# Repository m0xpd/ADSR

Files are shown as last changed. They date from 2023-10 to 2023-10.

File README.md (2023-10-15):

# ADSR
A Looping Version of the YuSynth ADSR

# Background

I decided to build a new envelope generator back in December 2022 to supplement / replace my old AR generators made from [MFOS](http://musicfromouterspace.com/) designs and my 
own ["ADSRduino"](https://github.com/m0xpd/ADSRduino).

I already knew Yves Usson's excellent [YuSynth site](https://yusynth.net/Modular/index_en.html) (having published a Eurorack version of the ['Simple VCA'](https://github.com/m0xpd/YuSynth-VCA-for-Eurorack)), and was interested by a comment on 
[Eddy Bergman's website](https://www.eddybergman.com/2020/03/synthesizer-build-part-24-adsr-with.html) about the YuSynth ADSR.

Eddy said:

> "I can say without any doubt that this design is perfect if you want a good and reliable ADSR to pair with your VCA or to drive a filter. " 

That settled it - I would make a Eurorack version of Yves' 7555-based design. However, having added looping to my ADSRduino, 
I decided that I would also like to include the same looping functionality on the new envelope generator. 

So - here it is. A version of the YuSynth 7555 ADSR in 8HP with looping...

<p width=100%, align="center">
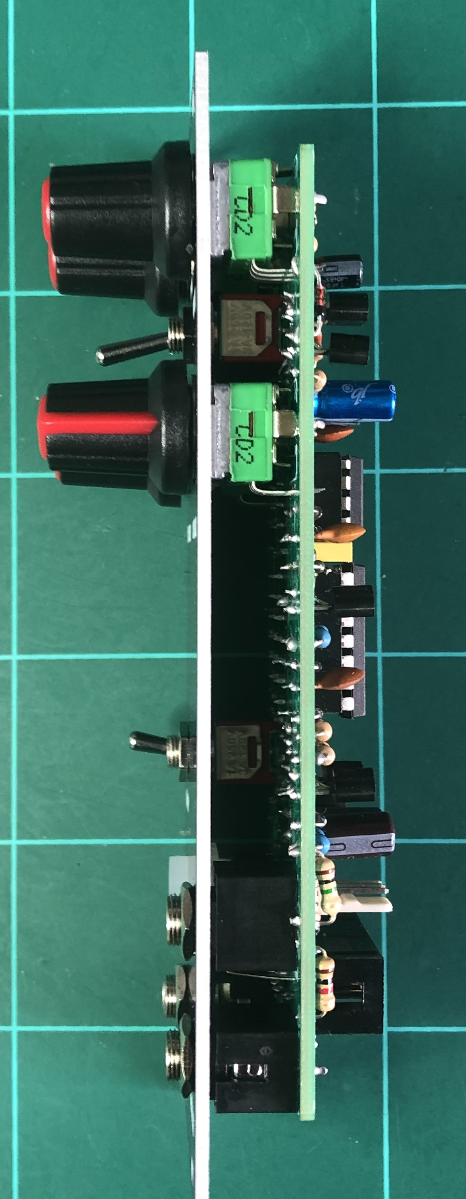
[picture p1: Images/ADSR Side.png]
 &nbsp &nbsp &nbsp &nbsp &nbsp &nbsp &nbsp &nbsp 
</p>

# Circuit Details

The schematic is seen below (click for a full-sized version and/or download from the 'images' folder).

<p width=100%, align="center">
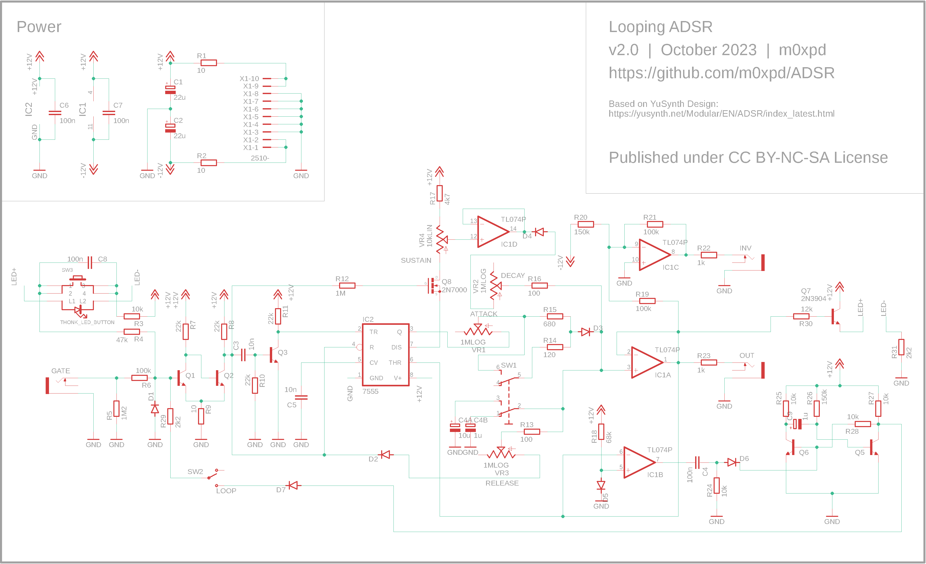
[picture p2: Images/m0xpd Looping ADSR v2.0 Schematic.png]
 
</p>

You will see that I follow Yves' original schematic pretty closely, apart from the addition of the elements required to realise the 
looping functionality. These are:
* a comparator (IC1B) to detect when the envelope falls below the PN junction drop (over D5)
* a positive edge detector (R24/C4/D6) to get a trigger when the envelope falls below the PN junction drop and
* a one-shot monostable multivibrator (Q5,6 etc), to generate a defined pulse from this trigger, 

which is applied via D7 back to the input stage. If the looping switch (SW2) is set appropriately, this pulse can re-trigger the 
envelope and cause 'looping'.

The old-school transistor one-shot is included because I didn't want to add another IC package (having already 'spent' the last stage 
of IC1 on the comparator task).

Other minor departures from Yves' "words and music" include a reduction in input resistor R6 (I had trouble with the specified 1M) and 
substitution of a 2N7000 for Yves' specified BS170 (I see others have had difficuty sourcing these rarer FETs and the garden-variety 
2N7000 works fine). 

I also chose to use once again the lovely [low-profile push button](https://www.thonk.co.uk/shop/low-profile-led-buttons/) as both 
manual gate switch and indicator. It is the right height to work with [Thonkiconns](https://www.thonk.co.uk/shop/thonkiconn/) and [Alpha pots](https://www.thonk.co.uk/shop/alpha-9mm-pots-vertical-t18/), which makes mechanical assembly a breeze.

# Construction Details

Full details of the PCB are given in the [PCB folder](PCB), which includes a .sch and .brd file, developed in EAGLE.

A front panel is decribed by a Kicad project in the [Front Panel folder.](Front%20Panel)

My original boards and Front panel (seen in the images above) were made by JLC, who did their usual competent job. 

The images show the v0.1 boards, which include a Molex KK connector for power which is not on the present V2.0 design. They also have 
different silkscreening, influencing most significantly the licensing...

# Licensing

<p width=100%, align="left">
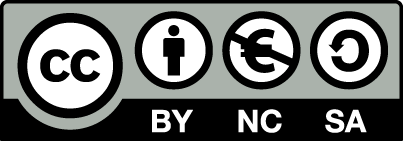
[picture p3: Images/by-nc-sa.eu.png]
 
</p>

Yves is clear on the position with copyright on his website:

> "All circuits, schematics, printed circuit board, panel design and associated data published on (yusynth.net) can be used for private use only." 

and:

> "The projects of (yusynth.net) may be build for personal, private usage or educative purpose. Commercial exploitation of the schematics, circuits, 
front panels and software shown on (yusynth.net), is not permitted without a formal agreement with (Yves Usson)".

Accordingly, **the copyright for the core of this ADSR circuit rests with Yves and no commercial exploitation is permitted**.

I have reflected this in the [License](LICENSE.txt) for the looping Eurorack version presented in this repository.

This work is licensed under a
[Creative Commons Attribution-NonCommercial-ShareAlike 4.0 International License.](https://creativecommons.org/licenses/by-nc-sa/4.0/deed.en)

# Specifications

The looping ADSR is 8HP wide and extends 25mm behind the front panel.

It consumes:

7.1mA from the 12V rail (max current in looping mode; quiescent current drain is 3.7mA)  

1.1mA from the -12V rail (in all conditions) 

nothing from the 5V rail.

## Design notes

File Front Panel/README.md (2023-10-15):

This folder contains a design for a Front Panel for the Looping ADSR envelope generator.

<p width=100%, align="center">
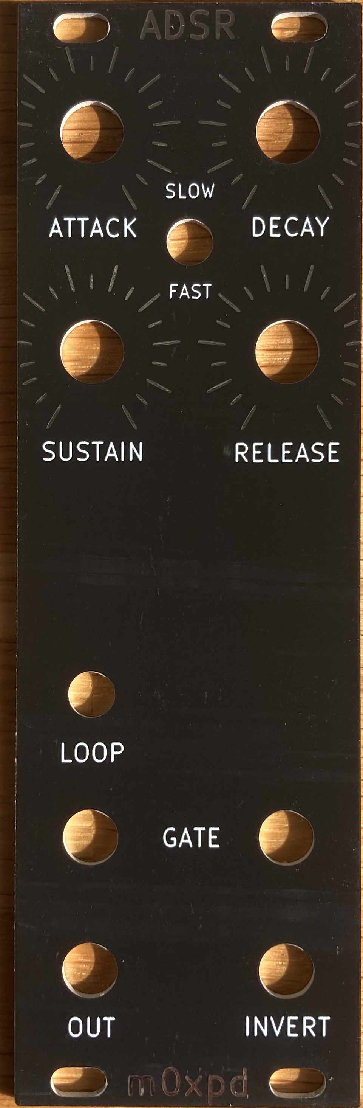
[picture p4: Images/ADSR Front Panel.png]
 
</p>

The panel design is expressed as a Kicad project.

The prototype panel in the image above was maanufactured by JLC. Their charges for aluminium panels has increased dramatically 
since the prototype was produced - alternatives in PCB material might be preferred!

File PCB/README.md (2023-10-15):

This folder contains design files for the m0xpd Looping ADSR.

There is a schematic file and a board file, developed in the EAGLE editor.

There is also a [BoM](m0xpd%20Looping%20ADSR%20v2.0%20Bill%20of%20Materials.txt), in the EAGLE's rather clumsy format.

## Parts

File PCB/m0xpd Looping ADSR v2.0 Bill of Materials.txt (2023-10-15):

Partlist exported from /Users/pauldarlington/Documents/EAGLE/projects/555 ADSR/m0xpdLooping ADSR v2.0.sch at 15/10/2023 13:20

Part Value            Device           Package            Description                                                       MF MPN         OC_FARNELL OC_NEWARK POPULARITY SPICEPREFIX
C1   22u              CPOL-EUE2.5-5    E2,5-5             POLARIZED CAPACITOR, European symbol                                                                  16         C          
C2   22u              CPOL-EUE2.5-5    E2,5-5             POLARIZED CAPACITOR, European symbol                                                                  16         C          
C3   10n              C-EU050-025X075  C050-025X075       CAPACITOR, European symbol                                                                            29         C          
C4   100n             C-EU050-025X075  C050-025X075       CAPACITOR, European symbol                                                                            29         C          
C4A  10u              CPOL-EUE2.5-5    E2,5-5             POLARIZED CAPACITOR, European symbol                                                                  16         C          
C4B  1u               CPOL-EUE2.5-5    E2,5-5             POLARIZED CAPACITOR, European symbol                                                                  16         C          
C5   10n              C-EU050-025X075  C050-025X075       CAPACITOR, European symbol                                                                            29         C          
C6   100n             C-EU050-025X075  C050-025X075       CAPACITOR, European symbol                                                                            29         C          
C7   100n             C-EU050-025X075  C050-025X075       CAPACITOR, European symbol                                                                            29         C          
C8   100n             C-EU025-030X050  C025-030X050       CAPACITOR, European symbol                                                                            14         C          
C9   1u               CPOL-EUE2.5-5    E2,5-5             POLARIZED CAPACITOR, European symbol                                                                  16         C          
D1   1N4148DO35-7     1N4148DO35-7     DO35-7             DIODE                                                                                                 58                    
D2   1N4148DO35-7     1N4148DO35-7     DO35-7             DIODE                                                                                                 58                    
D3   1N4148DO35-7     1N4148DO35-7     DO35-7             DIODE                                                                                                 58                    
D4   1N4148DO35-7     1N4148DO35-7     DO35-7             DIODE                                                                                                 58                    
D5   1N4148DO35-7     1N4148DO35-7     DO35-7             DIODE                                                                                                 58                    
D6   1N4148DO35-7     1N4148DO35-7     DO35-7             DIODE                                                                                                 58                    
D7   1N4148DO35-7     1N4148DO35-7     DO35-7             DIODE                                                                                                 58                    
GATE THONKICONNNEW    THONKICONNNEW    WQP-PJ301M-12_JACK 3.5mm socket for Eurorack modular synths                                                                                    
IC1  TL074P           TL074P           DIL14              OP AMP                                                                                                0                     
IC2  7555             7555             DIL08              CMOS 555 timer                                                                                                              
INV  THONKICONNNEW    THONKICONNNEW    WQP-PJ301M-12_JACK 3.5mm socket for Eurorack modular synths                                                                                    
OUT  THONKICONNNEW    THONKICONNNEW    WQP-PJ301M-12_JACK 3.5mm socket for Eurorack modular synths                                                                                    
Q1   2N3904           2N3904           TO92               NPN Transistor                                                                                        0                     
Q2   2N3904           2N3904           TO92               NPN Transistor                                                                                        0                     
Q3   2N3904           2N3904           TO92               NPN Transistor                                                                                        0                     
Q5   2N3904           2N3904           TO92               NPN Transistor                                                                                        0                     
Q6   2N3904           2N3904           TO92               NPN Transistor                                                                                        0                     
Q7   2N3904           2N3904           TO92               NPN Transistor                                                                                        0                     
Q8   2N7000           2N7000           TO92               N-Channel Mosfet                                                                                                            
R1   10               R-EU_0204/7      0204/7             RESISTOR, European symbol                                                                             79         R          
R2   10               R-EU_0204/7      0204/7             RESISTOR, European symbol                                                                             79         R          
R3   10k              R-EU_0204/7      0204/7             RESISTOR, European symbol                                                                             79         R          
R4   47k              R-EU_0204/7      0204/7             RESISTOR, European symbol                                                                             79         R          
R5   1M2              R-EU_0204/7      0204/7             RESISTOR, European symbol                                                                             79         R          
R6   100k             R-EU_0204/7      0204/7             RESISTOR, European symbol                                                                             79         R          
R7   22k              R-EU_0204/7      0204/7             RESISTOR, European symbol                                                                             79         R          
R8   22k              R-EU_0204/7      0204/7             RESISTOR, European symbol                                                                             79         R          
R9   10               R-EU_0204/7      0204/7             RESISTOR, European symbol                                                                             79         R          
R10  22k              R-EU_0204/7      0204/7             RESISTOR, European symbol                                                                             79         R          
R11  22k              R-EU_0204/7      0204/7             RESISTOR, European symbol                                                                             79         R          
R12  1M               R-EU_0204/7      0204/7             RESISTOR, European symbol                                                                             79         R          
R13  100              R-EU_0204/7      0204/7             RESISTOR, European symbol                                                                             79         R          
R14  120              R-EU_0204/7      0204/7             RESISTOR, European symbol                                                                             79         R          
R15  680              R-EU_0204/7      0204/7             RESISTOR, European symbol                                                                             79         R          
R16  100              R-EU_0204/7      0204/7             RESISTOR, European symbol                                                                             79         R          
R17  4k7              R-EU_0204/7      0204/7             RESISTOR, European symbol                                                                             79         R          
R18  68k              R-EU_0204/7      0204/7             RESISTOR, European symbol                                                                             79         R          
R19  100k             R-EU_0204/7      0204/7             RESISTOR, European symbol                                                                             79         R          
R20  150k             R-EU_0204/7      0204/7             RESISTOR, European symbol                                                                             79         R          
R21  100k             R-EU_0204/7      0204/7             RESISTOR, European symbol                                                                             79         R          
R22  1k               R-EU_0204/7      0204/7             RESISTOR, European symbol                                                                             79         R          
R23  1k               R-EU_0204/7      0204/7             RESISTOR, European symbol                                                                             79         R          
R24  10k              R-EU_0204/7      0204/7             RESISTOR, European symbol                                                                             79         R          
R25  10k              R-EU_0204/7      0204/7             RESISTOR, European symbol                                                                             79         R          
R26  150k             R-EU_0204/7      0204/7             RESISTOR, European symbol                                                                             79         R          
R27  10k              R-EU_0204/7      0204/7             RESISTOR, European symbol                                                                             79         R          
R28  10k              R-EU_0204/7      0204/7             RESISTOR, European symbol                                                                             79         R          
R29  2k2              R-EU_0204/7      0204/7             RESISTOR, European symbol                                                                             79         R          
R30  12k              R-EU_0204/7      0204/7             RESISTOR, European symbol                                                                             79         R          
R31  2k2              R-EU_0204/7      0204/7             RESISTOR, European symbol                                                                             79         R          
SW1  TL46PO           TL46PO           TL4XPO             TINY SWITCH ON - ON                                                                                   1                     
SW2  SUBMINI_SPDT     SUBMINI_SPDT     SUBMINI_TOGGLE     Subminuature SPDT Toggle,                                                                                                   
SW3  THONK_LED_BUTTON THONK_LED_BUTTON LOW_PROFILE_BUTTON Sleek low-profile illuminated button with a choice of LED colours                                                           
VR1  1MLOG            9MM_SNAP-IN_POT_ 9MM_SNAP-IN_POT    9mm vertical snap-in pot, Alpha / Panasonic style                                                                           
VR2  1MLOG            9MM_SNAP-IN_POT_ 9MM_SNAP-IN_POT    9mm vertical snap-in pot, Alpha / Panasonic style                                                                           
VR3  1MLOG            9MM_SNAP-IN_POT_ 9MM_SNAP-IN_POT    9mm vertical snap-in pot, Alpha / Panasonic style                                                                           
VR4  10kLIN           9MM_SNAP-IN_POT_ 9MM_SNAP-IN_POT    9mm vertical snap-in pot, Alpha / Panasonic style                                                                           
X1   2510-            2510-            PAK100/2500-10     3M (TM) Pak 100 4-Wall Header                                     3M 2510-6002UB 9838244    46F4725   0

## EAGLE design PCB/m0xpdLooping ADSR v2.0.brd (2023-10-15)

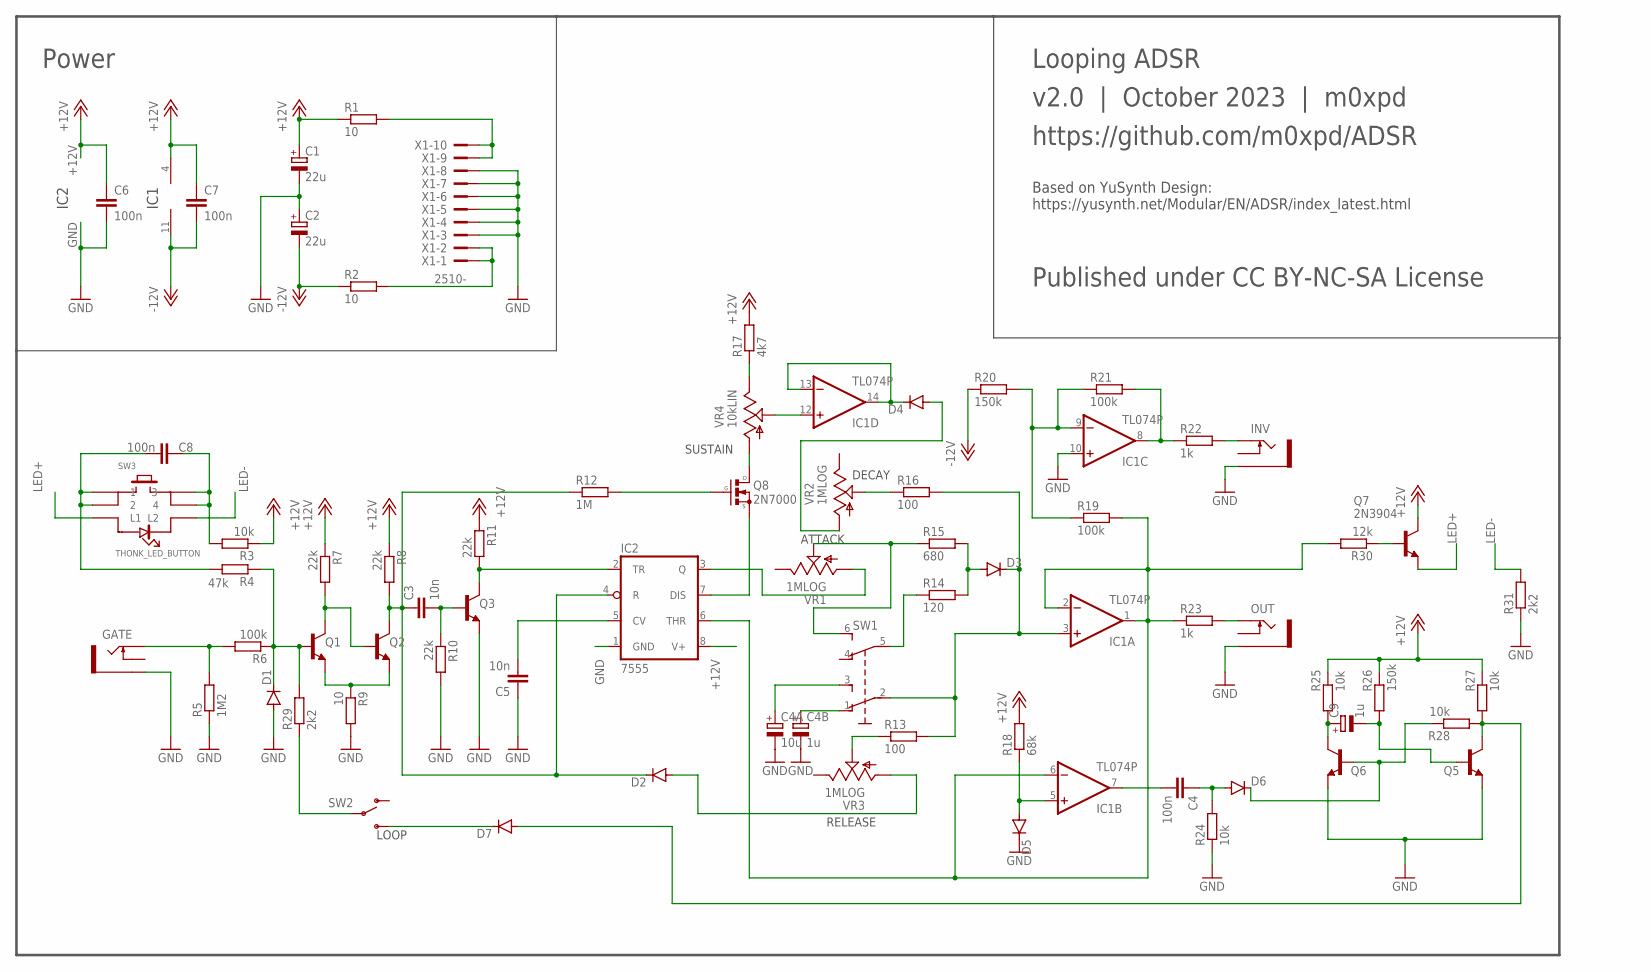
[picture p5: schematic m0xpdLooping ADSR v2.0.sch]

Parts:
C1, C2: 22u; E2,5-5
C3, C5: 10n; C050-025X075
C4, C6, C7: 100n; C050-025X075
C4A: 10u; E2,5-5
C4B, C9: 1u; E2,5-5
C8: 100n; C025-030X050
D1, D2, D3, D4, D5, D6, D7: 1N4148DO35-7; DO35-7
GATE: THONKICONNNEW; WQP-PJ301M-12_JACK
IC1: TL074P; DIL14
IC2: 7555; DIL08
INV: THONKICONNNEW; WQP-PJ301M-12_JACK
OUT: THONKICONNNEW; WQP-PJ301M-12_JACK
Q1, Q2, Q3, Q5, Q6, Q7: 2N3904; TO92
Q8: 2N7000; TO92
R1, R2, R9: 10; 0204/7
R3, R24, R25, R27, R28: 10k; 0204/7
R4: 47k; 0204/7
R5: 1M2; 0204/7
R6, R19, R21: 100k; 0204/7
R7, R8, R10, R11: 22k; 0204/7
R12: 1M; 0204/7
R13, R16: 100; 0204/7
R14: 120; 0204/7
R15: 680; 0204/7
R17: 4k7; 0204/7
R18: 68k; 0204/7
R20, R26: 150k; 0204/7
R22, R23: 1k; 0204/7
R29, R31: 2k2; 0204/7
R30: 12k; 0204/7
SW1: TL46PO; TL4XPO
SW2: SUBMINI_SPDT; SUBMINI_TOGGLE
SW3: THONK_LED_BUTTON; LOW_PROFILE_BUTTON
VR1, VR2, VR3: 1MLOG; 9MM_SNAP-IN_POT
VR4: 10kLIN; 9MM_SNAP-IN_POT
X1: 2510-; PAK100/2500-10

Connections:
+12V: C1.+, C6.1, C7.1, IC1.4 (V+), IC2.8 (V+), Q7.1 (C), R1.1, R3.1, R7.1, R8.1, R11.1, R17.2, R18.2, R25.2, R26.2, R27.2
-12V: C2.-, C7.2, IC1.11 (V-), R2.1, R20.1
GND: C1.-, C2.+, C4A.-, C4B.-, C5.1, C6.2, D1.A, D5.C, GATE.P$3_SLEEVE (SLEEVE), IC1.10 (+IN), IC2.1 (GND), INV.P$3_SLEEVE (SLEEVE), OUT.P$3_SLEEVE (SLEEVE), Q3.3 (E), Q5.3 (E), Q6.3 (E), R5.1, R9.2, R10.2, R24.1, R31.1, X1.3, X1.4, X1.5, X1.6, X1.7, X1.8
LED+: Q7.3 (E), SW3.L$1 (L1)
LED-: R31.2, SW3.L$2 (L2)
unnamed: R1.2, X1.9, X1.10
unnamed: GATE.P$1_TIP (TIP), R5.2, R6.2
unnamed: D1.C, Q1.2 (B), R4.1, R6.1, R29.2
unnamed: Q1.3 (E), Q2.3 (E), R9.1
unnamed: R2.2, X1.1, X1.2
unnamed: IC2.3 (Q), VR1.1 (A)
unnamed: Q1.1 (C), Q2.2 (B), R7.2
unnamed: C3.2, Q3.2 (B), R10.1
unnamed: IC2.2 (TR), Q3.1 (C), R11.2
unnamed: C5.2, IC2.5 (CV)
unnamed: C3.1, D2.C, IC2.4 (R), Q2.1 (C), R8.2, R12.1
unnamed: Q8.2 (G), R12.2
unnamed: IC2.7 (DIS), Q8.1 (S)
unnamed: D2.A, VR3.1 (A)
unnamed: Q8.3 (D), VR4.1 (A)
unnamed: R17.1, VR4.3 (E)
unnamed: R13.1, VR3.2 (S)
unnamed: R15.1, SW1.6 (S1), VR1.2 (S)
unnamed: R14.1, SW1.5 (P1)
unnamed: D3.A, R14.2, R15.2
unnamed: D3.C, IC1.3 (+IN), R13.2, R16.2, SW1.2
unnamed: R16.1, VR2.2 (S)
unnamed: C4A.+, SW1.3 (S)
unnamed: C4B.+, SW1.1 (O)
unnamed: IC1.1 (OUT), IC1.2 (-IN), IC1.6 (-IN), IC2.6 (THR), R19.2, R23.1, R30.2
unnamed: IC1.12 (+IN), VR4.2 (S)
unnamed: D4.C, IC1.13 (-IN), IC1.14 (OUT)
unnamed: D4.A, VR2.1 (A)
unnamed: D5.A, IC1.5 (+IN), R18.1
unnamed: IC1.9 (-IN), R19.1, R20.2, R21.1
unnamed: C4.2, IC1.7 (OUT)
unnamed: IC1.8 (OUT), R21.2, R22.1
unnamed: INV.P$1_TIP (TIP), R22.2
unnamed: OUT.P$1_TIP (TIP), R23.2
unnamed: C8.1, R3.2, SW3.P$3 (3), SW3.P$4 (4)
unnamed: C8.2, R4.2, SW3.P$1 (1), SW3.P$2 (2)
unnamed: C4.1, D6.A, R24.2
unnamed: D7.A, Q5.1 (C), R27.1, R28.1
unnamed: C9.+, Q6.1 (C), R25.1
unnamed: R29.1, SW2.COM (COMMON)
unnamed: C9.-, Q5.2 (B), R26.1
unnamed: D7.C, SW2.3 (S)
unnamed: D6.C, Q6.2 (B), R28.2
unnamed: Q7.2 (B), R30.1

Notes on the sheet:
SUSTAIN
DECAY
ATTACK
RELEASE
Looping ADSR
Based on YuSynth Design: https://yusynth.net/Modular/EN/ADSR/index_latest.html
v2.0 | October 2023 | m0xpd
https://github.com/m0xpd/ADSR
Published under CC BY-NC-SA License
LOOP
Power
IC1
IC2

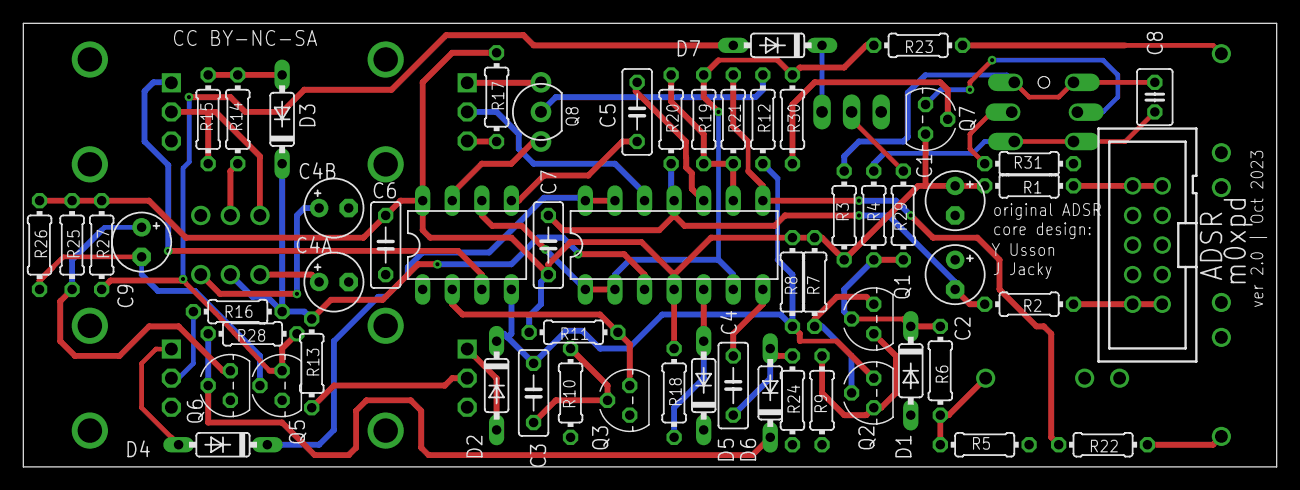
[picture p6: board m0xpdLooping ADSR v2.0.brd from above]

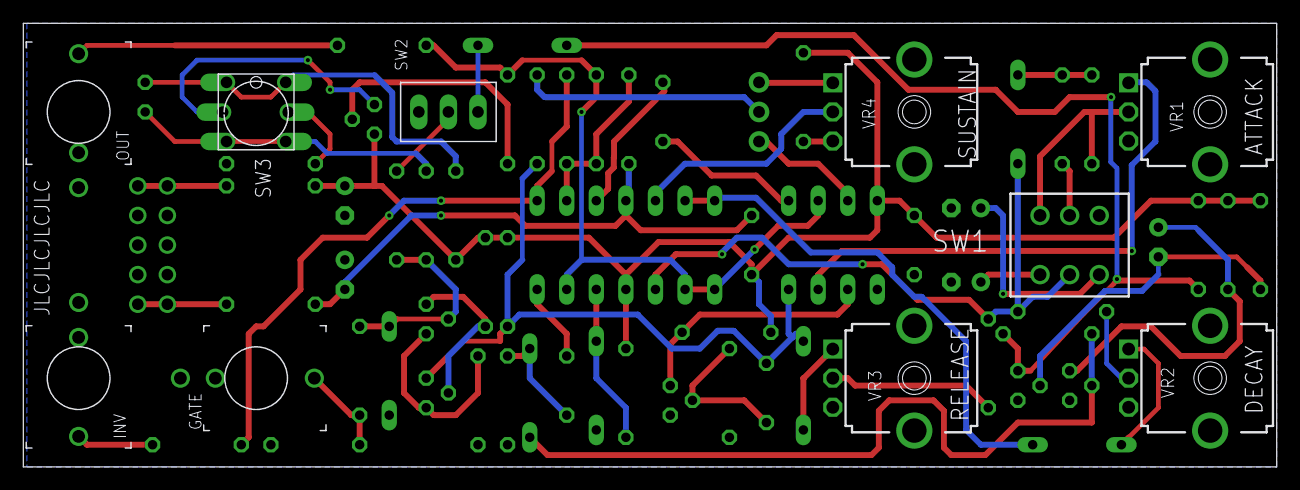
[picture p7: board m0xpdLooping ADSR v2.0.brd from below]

Board: 2 copper layers, 107.6 x 38.1 mm, 69 parts (10 on the bottom side), 49 nets.

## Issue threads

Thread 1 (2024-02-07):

Front panel design missing?

trygvelu, 2024-02-07:
Hi - first off, I really appreciate your effort on publishing schematics and background for your projects!
I'm just starting out with building some modules, and have produced a couple of your PCBs (ADSR and VCA). I am just finishing up the builds, after sourcing components. I thought I'd have a go at doing the front panels myself, but use the front panel in the project as a template. But when I open the front panel project in KiCad the schematic is empty.
I'm a novice at using KiCad, but the VCA front panel loads just fine, so I think there might be something off with this front panel project.

m0xpd, 2024-02-08:
Hi. Thanks for your kind comments.
I see what you mean about the ADSR Front Panel files - I have just uploaded a new set of files describing the same panel, which seem to constitute a complete KiCad project. I hope these will work properly for you.
Note that the schematics for all the PCBs are intentionally "empty" there is no electrical dimension to these panels.
Please let me know if these changes work for you.
Paul / m0xpd

trygvelu, 2024-02-08:
Tested, and now the panel comes up just fine in KiCad.
Thanks!

Closed 2024-02-08.

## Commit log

2023-10-15 Rename Looping ADSR.kicad_pcb to Front Panel/Looping ADSR.kicad_pcb
    [Looping ADSR.kicad_pcb]
2023-10-15 Rename Looping ADSR.kicad_pro to Front Panel/Looping ADSR.kicad_pro
2023-10-15 Rename Looping ADSR.kicad_sch to Front Panel/Looping ADSR.kicad_sch
    [Looping ADSR.kicad_sch]
2023-10-15 Rename m0xpdLooping ADSR v2.0.brd to PCB/m0xpdLooping ADSR v2.0.brd
    [m0xpdLooping ADSR v2.0.brd]
2023-10-15 Rename m0xpdLooping ADSR v2.0.sch to PCB/m0xpdLooping ADSR v2.0.sch
    [m0xpdLooping ADSR v2.0.sch]
2024-02-08 Rename Front Panel/Looping ADSR.kicad_pcb to Front Panel/OldFiles/Looping ADSR.kicad_pcb
    [Looping ADSR.kicad_pcb]
2024-02-08 Rename Front Panel/Looping ADSR.kicad_pro to Front Panel/OldFiles/Looping ADSR.kicad_pro
2024-02-08 Rename Front Panel/Looping ADSR.kicad_sch to Front Panel/OldFiles/Looping ADSR.kicad_sch
    [Looping ADSR.kicad_sch]
